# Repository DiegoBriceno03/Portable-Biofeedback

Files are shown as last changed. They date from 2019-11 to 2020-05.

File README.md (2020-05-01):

# Portable Biofeedback Device Repository

A repository that stores hardware and software files developed for the Portable Biofeedback Device, as worked on and built by students in the Electrical & Computer Engineering (ECE) Department of the College of Engineering & Computer Science (CECS) at the University of Central Florida (UCF) in Orlando, Florida.

The accompanying Android app was developed in Android Studio 3.5.3, making use of Android SDK/API 21 (Android 5).

All the schematics and layout is done in Kicad 5.14 along with custom libraries. These libraries are added under /Libraries.

These projects use custom path for its libraries. The custom Kicad Path variable ${KI_SDREPO} is used to increase portability. Custom variable points to the physical location of the /Libraries directory and must be declared under "Preferences > Configure Paths" setting before use.

## Group 11 Members

Roles are listed under each group member

+ Grace Brazil (EE)
  + Power circuit design
+ Diego Briceno (EE)
  + PCB design
+ Gustavo Diaz Galeas (CpE)
  + Phone app development
+ Nicholas Miller (CpE)
  + Firmware development

## Hardware

### Breakout Boards
- [x] MAX30101 Heart Rate / Pulse Oximeter Breakout Board REV -
- [x] Galvanic Skin Response Sensor (Groove Seed GSR Sensor design used: https://www.seeedstudio.com/Grove-GSR-sensor-p-1614.html.html)
- [x] Temperature Sensor Supporting Hardware
- [x] Battery Charging Managing circuit (BMS)
- [x] Power Regulation
Integration of these hardware is seen under ~/Prototyp_REV- 

## Software
### Phone App
- [x] Bluetooth backend
- [X] UI / UX

### Firmware
- [x] Heart Rate Data Processing Algorithm
- [x] Temperature Data Processing Algorithm
- [x] Galvanic Skin Resistance Data Processing Algorithm

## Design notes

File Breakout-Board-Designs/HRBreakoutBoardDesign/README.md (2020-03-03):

# MAX30101 Breakout Board

The Heart Rate Module for the biofeedback device is the MAX30101. Which comes with its internal LEDS and Photodiodes. In this library we have the layout done in KiCAD 5.1.5.

MAX30101 Breakout Schematic

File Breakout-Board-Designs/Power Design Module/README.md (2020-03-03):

# Power Design Module.

This module contains the design for the Portable biofeedback anxiety treatment device. 
It consist of a charging circuit (BQ24072) which is configured to charge a single cell LiPo(PKCELL 503035) 500mAh battery. This design takes advantage of a Micro USB charging at CV of 4.2V and CC of 500mA.

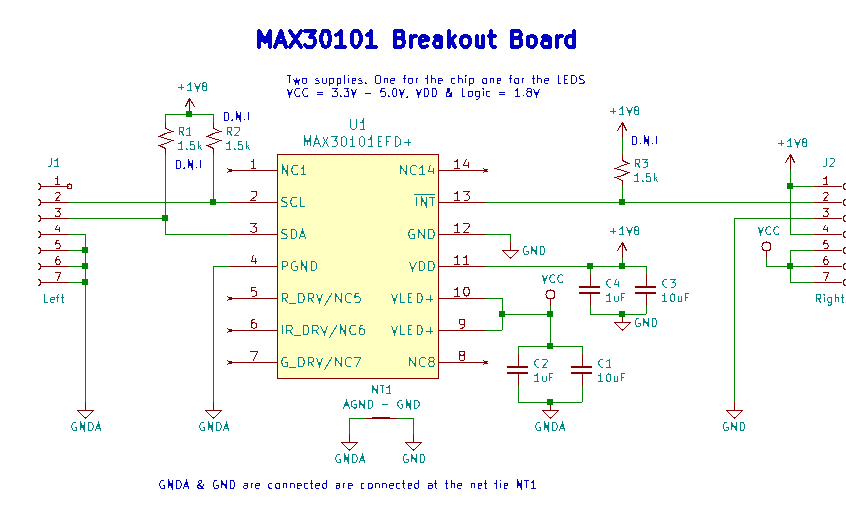
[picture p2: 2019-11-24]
Documentation/HRBreakoutBoard/Pictures/MAX30101_Schematic.png

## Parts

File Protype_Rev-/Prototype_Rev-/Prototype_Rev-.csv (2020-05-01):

Reference | Quantity | Value | Footprint | Datasheet | Manfacturing # | Rating | Tolerance | Description
C14 | 1 | 22uF | Capacitor_SMD:C_0603_1608Metric_Pad1.05x0.95mm_HandSolder | https://static6.arrow.com/aropdfconversion/3239fa20032553bf6ad0408d71d42cb72537ccc5/19-cl10a226mpcnube.pdf | CL10A226MPCNUBE | 10V
C15 | 1 | 100nF | Capacitor_SMD:C_0603_1608Metric_Pad1.05x0.95mm_HandSolder | https://www.mouser.com/datasheet/2/212/KEM_C1002_X7R_SMD-1102033.pdf | C0603C104K8RACTU | 10V
C19 | 1 | 22nF | Capacitor_SMD:C_0603_1608Metric_Pad1.05x0.95mm_HandSolder | https://www.mouser.com/datasheet/2/212/KEM_C1002_X7R_SMD-1102033.pdf | C0603C223K4RACTU | 10V
C3 C5 C24 C30 C26 C32 C25 C27 C31 C33 C20 | 11 | 1uF | Capacitor_SMD:C_0603_1608Metric_Pad1.05x0.95mm_HandSolder | https://www.mouser.com/datasheet/2/396/taiyo_yuden_12132018_mlcc11_hq_e-1510082.pdf | LMK107B7105MAHT | 10V | 20%
C4 C6 C23 C16 C22 C21 C17 C18 | 8 | 10uF | Capacitor_SMD:C_0805_2012Metric_Pad1.15x1.40mm_HandSolder | https://www.mouser.com/datasheet/2/396/mlcc02_e-1307760.pdf | LMK212B7106KG-TD | 10V
C7 C12 C13 C11 C1 C2 C10 | 7 | 0.1uF | Capacitor_SMD:C_0603_1608Metric_Pad1.05x0.95mm_HandSolder | https://www.mouser.com/datasheet/2/212/KEM_C1002_X7R_SMD-1102033.pdf | C0603C104K8RACTU | 10V
C8 C9 C29 C28 | 4 | 4.7uF | Capacitor_SMD:C_0603_1608Metric_Pad1.05x0.95mm_HandSolder | https://www.mouser.com/datasheet/2/281/murata_03052018_GRM_Series_1-1310166.pdf | GRM188Z71A475ME15D | 10V
D1 D2 D3 | 3 | DESD5V0S1BB-7 | Diode_SMD:D_SOD-523 | https://www.mouser.com/datasheet/2/115/DESD5V0S1BB-218358.pdf | DESD5V0S1BB-7
D5 D4 D6 | 3 | Red | LED_SMD:LED_0603_1608Metric_Pad1.05x0.95mm_HandSolder | https://www.mouser.com/datasheet/2/348/smld12-e-1510650.pdf | 599-0110-007F
D7 | 1 | Green | LED_SMD:LED_0603_1608Metric_Pad1.05x0.95mm_HandSolder | https://www.mouser.com/datasheet/2/348/smld12-e-1510650.pdf | SMLD12EN1WT86
J1 | 1 | USB_B_Micro | Connector_USB:USB_Micro-B_Molex-105017-0001 | ~ | 105017-0001
J2 | 1 | Interface Hub | 1053141114:1053141110 | https://www.molex.com/pdm_docs/sd/1053141114_sd.pdf
J3 | 1 | Conn_01x02 | Connector_JST:JST_EH_B3B-EH-A_1x03_P2.50mm_Vertical | https://www.digikey.com/product-detail/en/jst-sales-america-inc/B3B-EH-A-LF-SN/455-1612-ND/926521
JP1 | 1 | TMR OFF | Jumper:SolderJumper-2_P1.3mm_Open_RoundedPad1.0x1.5mm | ~
JP2 | 1 | Charger / Battery Bypass | Connector_PinHeader_2.54mm:PinHeader_1x03_P2.54mm_Vertical | ~
L1 | 1 | 1uH | IHLP2020BZER1R0M0:IHLP2020BZER1R0M01 | https://www.vishay.com/docs/34253/ihlp-2020bz-01.pdf | IHLP2020BZER1R0M01
NT1 | 1 | AGND - GND | NetTie:NetTie-2_SMD_Pad0.5mm | ~
Q1 Q2 | 2 | SS8050-G | Package_TO_SOT_SMD:SOT-23 | https://www.mouser.com/datasheet/2/80/SS8050-G_RevA181526-1481562.pdf | SS8050-G
Q3 | 1 | 2N7002ET7G | Package_TO_SOT_SMD:SOT-23 | https://www.mouser.com/datasheet/2/308/2N7002E-D-1571276.pdf | 2N7002ET7G
Q4 | 1 | BSS83P | Package_TO_SOT_SMD:SOT-23 | https://www.mouser.com/datasheet/2/196/BSS83P_Rev1_6-1730820.pdf | BSS83P
R11 R10 R35 | 3 | 530R | Resistor_SMD:R_0603_1608Metric_Pad1.05x0.95mm_HandSolder | ~ | RN731JTTD5300F100
R12 R13 | 2 | 4.7k | Resistor_SMD:R_0603_1608Metric_Pad1.05x0.95mm_HandSolder | ~ | SFR03EZPF4701
R18 R17 R30 R31 R33 R34 R39 R40 R43 R44 | 10 | 100k | Resistor_SMD:R_0603_1608Metric_Pad1.05x0.95mm_HandSolder | ~ | CRCW0603100KFKEAC
R20 R15 R19 R14 R37 | 5 | 200k | Resistor_SMD:R_0603_1608Metric_Pad1.05x0.95mm_HandSolder | ~ | SDR03EZPF2003
R21 | 1 | 1M | Resistor_SMD:R_0603_1608Metric_Pad1.05x0.95mm_HandSolder | ~ | RC0603FR-071ML
R22 R23 R5 | 3 | 1.5k | Resistor_SMD:R_0603_1608Metric_Pad1.05x0.95mm_HandSolder | ~ | RC0603FR-071K5L | 1/8W
R3 | 1 | 22.1k | Resistor_SMD:R_0603_1608Metric_Pad1.05x0.95mm_HandSolder | https://www.mouser.com/datasheet/2/427/dcrcwe3-1762152.pdf | CRCW060322K1FKEB
R32 | 1 | 1.78k | Resistor_SMD:R_0603_1608Metric_Pad1.05x0.95mm_HandSolder | ~ | CR0603-FX-1781ELF
R36 | 1 | 320R | Resistor_SMD:R_0603_1608Metric_Pad1.05x0.95mm_HandSolder | ~ | RT0603DRE07320RL
R38 | 1 | 49.9k | Resistor_SMD:R_0603_1608Metric_Pad1.05x0.95mm_HandSolder | ~ | CRCW060349K9FKEAC
R4 | 1 | 47.5k | Resistor_SMD:R_0603_1608Metric_Pad1.05x0.95mm_HandSolder | https://www.mouser.com/datasheet/2/427/crcwce3-1762584.pdf | CRCW060347K5FKEAC
R6 R29 | 2 | 2K | Resistor_SMD:R_0603_1608Metric_Pad1.05x0.95mm_HandSolder | ~ | RN73R1JTTD2001B25
R7 R1 R2 R28 R27 R25 R26 R24 R16 R42 R41 | 11 | 10k | Resistor_SMD:R_0603_1608Metric_Pad1.05x0.95mm_HandSolder | ~ | SG73G1JTTD1002D
R8 R9 | 2 | 0R | Resistor_SMD:R_0603_1608Metric_Pad1.05x0.95mm_HandSolder | ~ | CRCW06030000Z0EAC
SW1 | 1 | EN | Button_Switch_SMD:SW_SPST_PTS810 | https://dznh3ojzb2azq.cloudfront.net/products/Tactile/PTS810/documents/datasheet.pdf | SKRKAEE020
SW2 | 1 | BOOT | Button_Switch_SMD:SW_SPST_PTS810 | https://dznh3ojzb2azq.cloudfront.net/products/Tactile/PTS810/documents/datasheet.pdf | SKRKAEE020
U1 | 1 | MAX30101EFD+ | MAX30101:MAX30101EFD+ | https://datasheets.maximintegrated.com/en/ds/MAX30101.pdf
U2 | 1 | CP2102N-A01-GQFN28 | Package_DFN_QFN:QFN-28-1EP_5x5mm_P0.5mm_EP3.35x3.35mm | https://www.silabs.com/documents/public/data-sheets/cp2102n-datasheet.pdf
U3 | 1 | MAX5419LETA+ | Package_DFN_QFN:DFN-8-1EP_3x3mm_P0.5mm_EP1.66x2.38mm | https://www.mouser.com/datasheet/2/256/MAX5419-1513850.pdf
U4 | 1 | LM324 | Package_SO:TSSOP-14_4.4x5mm_P0.65mm | http://www.ti.com/lit/ds/symlink/lm2902-n.pdf
U5 | 1 | ESP32-WROOM-32 | RF_Module:ESP32-WROOM-32 | https://www.espressif.com/sites/default/files/documentation/esp32-wroom-32_datasheet_en.pdf
U6 | 1 | TPS61232DRCR | TPS61232DRCR:TPS61232DRCR | https://www.ti.com/lit/ds/symlink/tps61232.pdf
U7 | 1 | BQ24072TRGTR | BQ24072TRGTR:BQ24072TRGTR | http://www.ti.com/lit/ds/slus937c/slus937c.pdf
U8 | 1 | TLV75718PDBVR | Package_TO_SOT_SMD:SOT-23-5 | http://www.ti.com/lit/ds/symlink/tlv757p.pdf?HQS=TI-null-null-mousermode-df-pf-null-wwe&DCM=yes&distId=26
U9 | 1 | TLV75733PDBVR | Package_TO_SOT_SMD:SOT-23-5 | http://www.ti.com/lit/ds/symlink/tlv757p.pdf?HQS=TI-null-null-mousermode-df-pf-null-wwe&DCM=yes&distId=26

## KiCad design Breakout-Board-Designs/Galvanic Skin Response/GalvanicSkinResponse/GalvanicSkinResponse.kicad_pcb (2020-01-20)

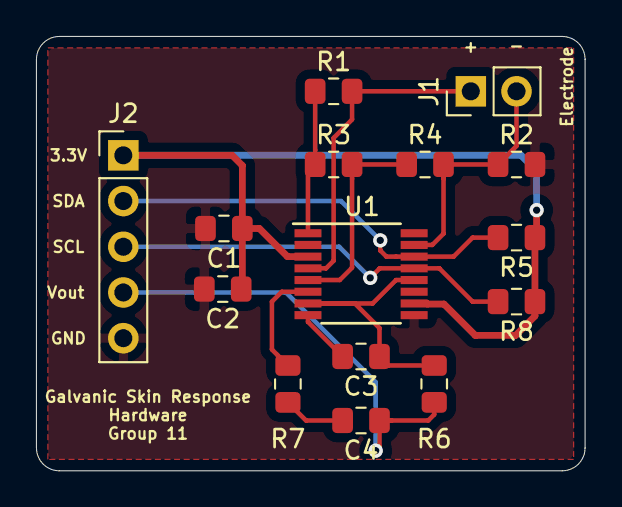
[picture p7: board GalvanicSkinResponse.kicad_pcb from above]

Board: 2 copper layers, 30.5 x 24.1 mm, 15 parts (0 on the bottom side), 13 nets.

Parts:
C1: 1nF; C_0805_2012Metric_Pad1.15x1.40mm_HandSolder
C2, C4: 10nF; C_0805_2012Metric_Pad1.15x1.40mm_HandSolder
C3: 150pF; C_0805_2012Metric_Pad1.15x1.40mm_HandSolder
J1: Electrodes; PinHeader_1x02_P2.54mm_Vertical
J2: Control; PinHeader_1x05_P2.54mm_Vertical
R1, R6, R7: 100R; R_0805_2012Metric_Pad1.15x1.40mm_HandSolder
R2: 50R; R_0805_2012Metric_Pad1.15x1.40mm_HandSolder
R3: 100k; R_0805_2012Metric_Pad1.15x1.40mm_HandSolder
R4, R5, R8: 15k; R_0805_2012Metric_Pad1.15x1.40mm_HandSolder
U1: PGA309; TSSOP-16_4.4x5mm_P0.65mm

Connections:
+3V3: C1.1, C2.1, J2.1, R5.1, R8.1, U1.3, U1.10
GND: C1.2, C2.2, J2.5, R2.2, U1.2, U1.9, U1.11
unnamed: C3.1, R6.2, U1.7, U1.12
unnamed: C3.2, U1.8
unnamed: C4.2, R7.1
unnamed: J1.1, R1.2, U1.4
unnamed: J1.2, R2.1, R4.2, U1.15
unnamed: R1.1, R3.1, U1.1
unnamed: R3.2, R4.1, U1.5
unnamed: R7.2, U1.6
SCL: J2.3, R8.2, U1.13
SDA: J2.2, R5.2, U1.14
V_out: C4.1, J2.4, R6.1

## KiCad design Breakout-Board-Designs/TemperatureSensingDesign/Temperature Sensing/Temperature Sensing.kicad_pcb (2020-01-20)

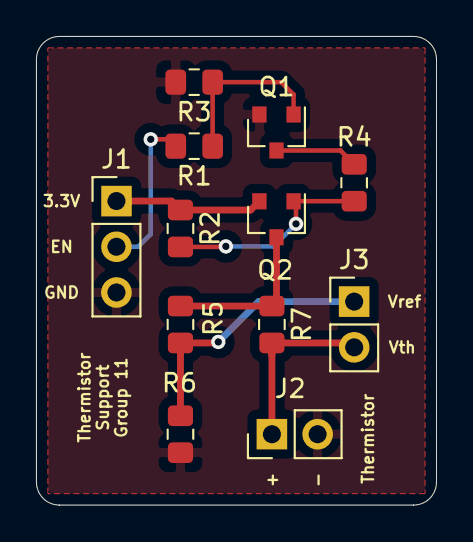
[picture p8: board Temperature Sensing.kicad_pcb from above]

Board: 2 copper layers, 22.2 x 26.0 mm, 12 parts (0 on the bottom side), 9 nets.

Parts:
J1: POW / Control; PinHeader_1x03_P2.54mm_Vertical
J2: Termistor 10k; PinHeader_1x02_P2.54mm_Vertical
J3: ADC Inputs; PinHeader_1x02_P2.54mm_Vertical
Q1: 2N7002E; SOT-23
Q2: BSS83P; SOT-23
R1, R2, R3, R4, R6: 10k; R_0805_2012Metric_Pad1.15x1.40mm_HandSolder
R5, R7: 20k; R_0805_2012Metric_Pad1.15x1.40mm_HandSolder

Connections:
/+3.3V: J1.1, Q2.2, R2.1
/GPIO_EN: J1.2, R1.2
/Vref: J3.1, R5.2, R6.1
/Vth: J2.1, J3.2, R7.2
GND: J1.3, J2.2, Q1.2, R3.2, R6.2
unnamed: Q1.1, R1.1, R3.1
unnamed: Q1.3, R4.2
unnamed: Q2.1, R2.2, R4.1
unnamed: Q2.3, R5.1, R7.1

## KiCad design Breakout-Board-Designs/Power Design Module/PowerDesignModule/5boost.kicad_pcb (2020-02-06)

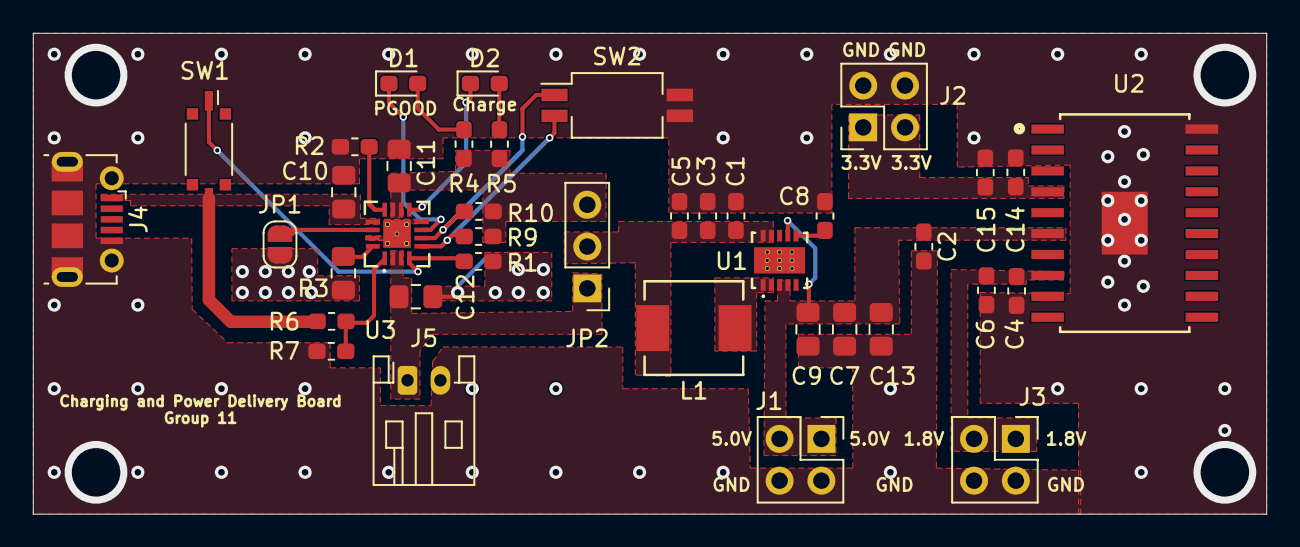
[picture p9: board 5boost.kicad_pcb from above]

Board: 2 copper layers, 74.9 x 29.2 mm, 39 parts (0 on the bottom side), 21 nets.

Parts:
C1, C3, C5: 10μF; C_0603_1608Metric_Pad1.05x0.95mm_HandSolder
C2, C4, C14: 0.1uF; C_0603_1608Metric_Pad1.05x0.95mm_HandSolder
C6, C15: 10uF; C_0603_1608Metric_Pad1.05x0.95mm_HandSolder
C7, C9, C13: 10uF; C_0805_2012Metric_Pad1.15x1.40mm_HandSolder
C8: 22nF; C_0603_1608Metric_Pad1.05x0.95mm_HandSolder
C10: 1uF; C_0805_2012Metric_Pad1.15x1.40mm_HandSolder
C11, C12: 4.7uF; C_0805_2012Metric_Pad1.15x1.40mm_HandSolder
D1: Red; LED_0603_1608Metric_Pad1.05x0.95mm_HandSolder
D2: Green; LED_0603_1608Metric_Pad1.05x0.95mm_HandSolder
J1: 5.0V; PinSocket_2x02_P2.54mm_Vertical
J2: 3.3V; PinSocket_2x02_P2.54mm_Vertical
J3: 1.8V; PinSocket_2x02_P2.54mm_Vertical
J4: USB_B_Micro; USB_Micro-B_Molex-105017-0001
J5: Battery Output; JST_PH_S2B-PH-K_1x02_P2.00mm_Horizontal
JP1: TMR OFF; SolderJumper-2_P1.3mm_Open_RoundedPad1.0x1.5mm
JP2: Charger / Battery Bypass; PinHeader_1x03_P2.54mm_Vertical
L1: 1uH; IHLP2020BZER1R0M01
R1, R2: 2K; R_0603_1608Metric_Pad1.05x0.95mm_HandSolder
R3: 1.78k; R_0805_2012Metric_Pad1.15x1.40mm_HandSolder
R4: 530R; R_0603_1608Metric_Pad1.05x0.95mm_HandSolder
R5: 320R; R_0603_1608Metric_Pad1.05x0.95mm_HandSolder
R6: 200k; R_0603_1608Metric_Pad1.05x0.95mm_HandSolder
R7: 49.9k; R_0603_1608Metric_Pad1.05x0.95mm_HandSolder
R9, R10: 10k; R_0603_1608Metric_Pad1.05x0.95mm_HandSolder
SW1: Charge Disable Switch; SW_DIP_SPSTx01_Slide_Copal_CVS-01xB_W5.9mm_P1mm
SW2: Input Current Selection; SW_DIP_SPSTx02_Slide_Copal_CHS-02B_W7.62mm_P1.27mm
U1: DRC_S-PVSON-N10; TPS61232DRCR
U2: TPPM0110DWPR
U3: BQ24072TRGTR

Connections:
/1.8V: C4.1, C6.1, J3.1, J3.2, U2.8
/3.3V: C14.1, C15.1, J2.1, J2.2, U2.4
/5.0V: C2.1, C7.1, C9.1, C13.1, J1.1, J1.2, U1.3, U1.4, U1.7, U2.6
/ChargingCircuit/BATT+: C12.1, J5.1, JP2.1, U3.2, U3.3
/Voutbat: C1.2, C3.2, C5.2, JP2.2, L1.1, U1.9, U1.10
EN1: R10.2, SW2.1, U3.6
EN2: R9.1, SW2.2, U3.5
GND: C1.1, C2.2, C3.1, C4.2, C5.1, C6.2, C7.2, C8.2, C9.2, C10.2, C11.2, C12.2, C13.2, C14.2, C15.2, J1.3, J1.4, J2.3, J2.4, J3.3, J3.4, J4.5, J4.6, J5.2, JP1.2, R1.2, R2.2, R3.2, R7.2, SW2.3, SW2.4, U1.11, U2.20, U2.21, U3.8, U3.15, U3.17
unnamed: C8.1, U1.6
unnamed: D1.1, U3.7
unnamed: D1.2, R4.2
unnamed: D2.1, U3.9
unnamed: D2.2, R5.2
unnamed: JP1.1, U3.14
unnamed: L1.2, U1.1, U1.2
unnamed: R2.1, U3.12
unnamed: R3.1, U3.16
unnamed: R6.2, R7.1, U3.1
Vbus: C10.1, J4.1, R6.1, SW1.2, U3.13
Vout: C11.1, JP2.3, R4.1, R5.1, R9.2, R10.1, U3.10, U3.11
~CE: R1.1, SW1.1, U3.4

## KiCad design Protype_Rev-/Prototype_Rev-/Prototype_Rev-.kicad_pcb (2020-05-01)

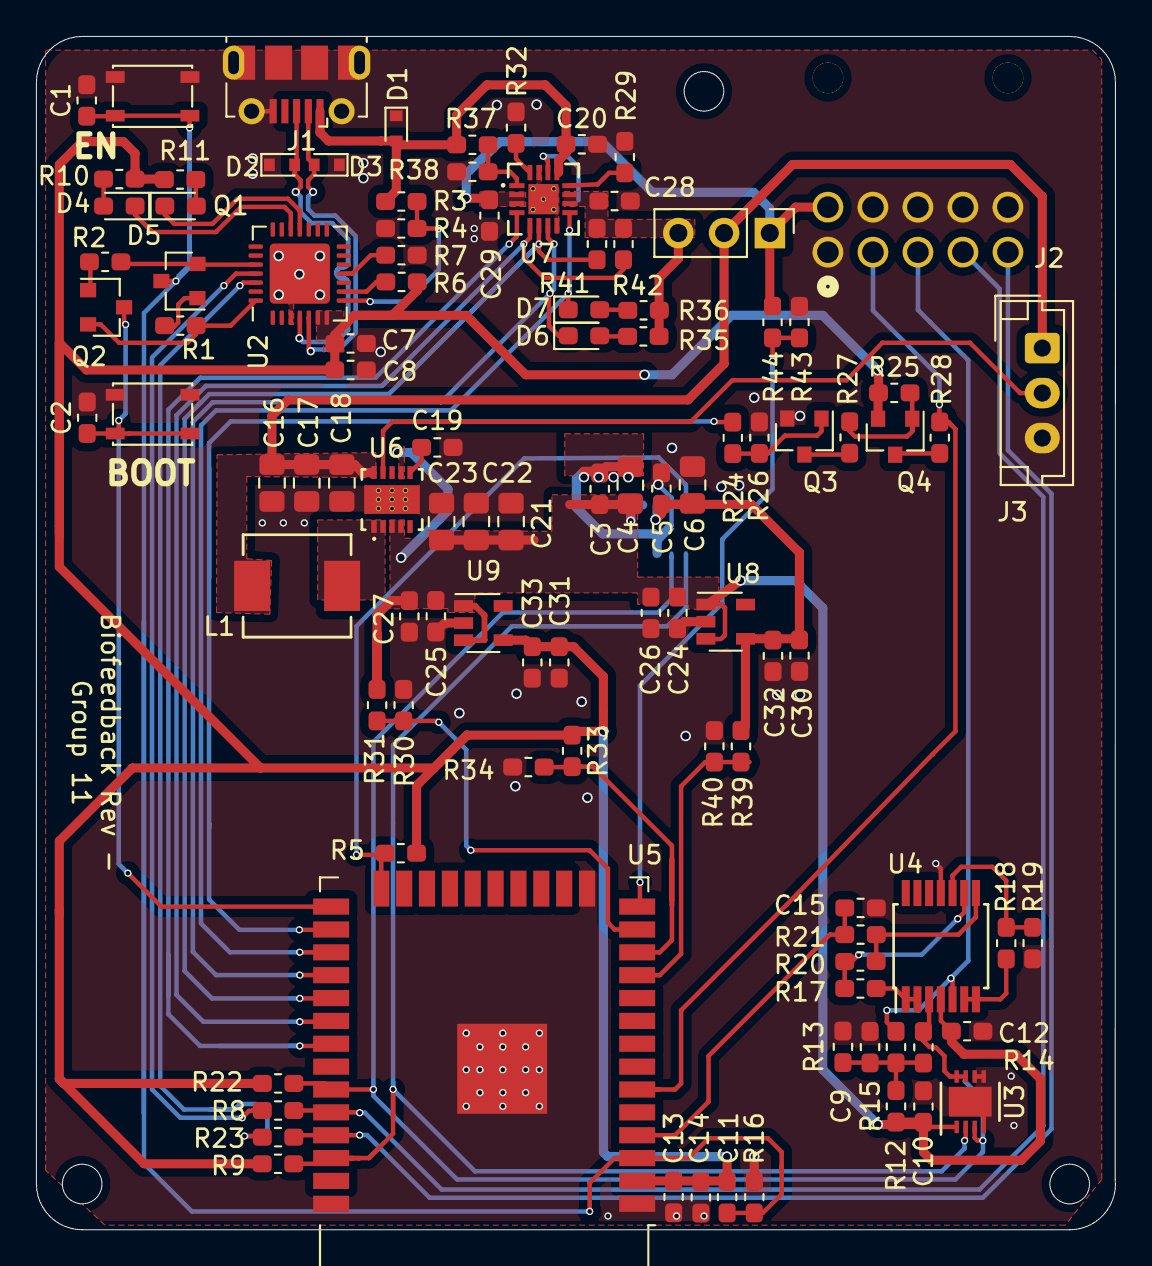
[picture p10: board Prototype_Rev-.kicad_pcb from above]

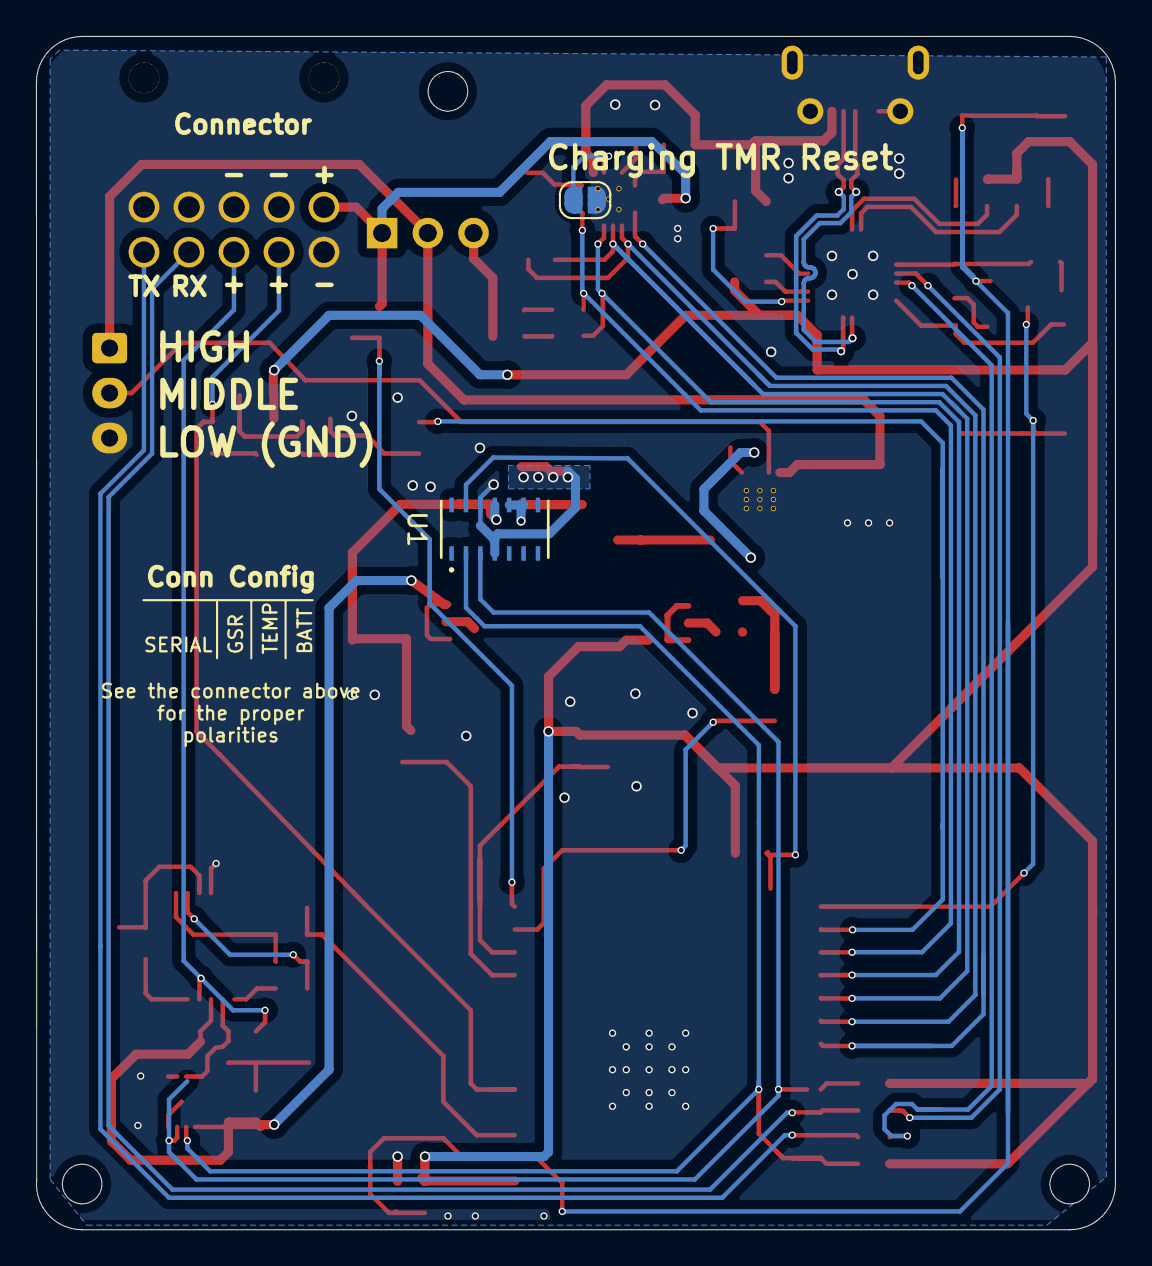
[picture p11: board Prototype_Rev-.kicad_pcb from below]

Board: 2 copper layers, 59.9 x 66.3 mm, 106 parts (3 on the bottom side), 64 nets.

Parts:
C1, C2, C7, C10, C11, C12, C13: 0.1uF; C_0603_1608Metric_Pad1.05x0.95mm_HandSolder
C3, C5, C20, C24, C25, C26, C27, C30, C31, C32, C33: 1uF; C_0603_1608Metric_Pad1.05x0.95mm_HandSolder
C4, C6, C16, C17, C18, C21, C22, C23: 10uF; C_0805_2012Metric_Pad1.15x1.40mm_HandSolder
C8, C9, C28, C29: 4.7uF; C_0603_1608Metric_Pad1.05x0.95mm_HandSolder
C14: 22uF; C_0603_1608Metric_Pad1.05x0.95mm_HandSolder
C15: 100nF; C_0603_1608Metric_Pad1.05x0.95mm_HandSolder
C19: 22nF; C_0603_1608Metric_Pad1.05x0.95mm_HandSolder
D1, D2, D3: DESD5V0S1BB-7; D_SOD-523
D4, D5, D6: Red; LED_0603_1608Metric_Pad1.05x0.95mm_HandSolder
D7: Green; LED_0603_1608Metric_Pad1.05x0.95mm_HandSolder
J1: USB_B_Micro; USB_Micro-B_Molex-105017-0001
J2: Interface Hub; 1053141110
J3: Conn_01x02; JST_EH_B3B-EH-A_1x03_P2.50mm_Vertical
JP1: TMR OFF; SolderJumper-2_P1.3mm_Open_RoundedPad1.0x1.5mm
JP2: Charger / Battery Bypass; PinHeader_1x03_P2.54mm_Vertical
L1: 1uH; IHLP2020BZER1R0M01
NT1: AGND - GND; NetTie-2_SMD_Pad0.5mm
Q1, Q2: SS8050-G; SOT-23
Q3: 2N7002ET7G; SOT-23
Q4: BSS83P; SOT-23
R1, R2, R7, R16, R24, R25, R26, R27, R28, R41, R42: 10k; R_0603_1608Metric_Pad1.05x0.95mm_HandSolder
R3: 22.1k; R_0603_1608Metric_Pad1.05x0.95mm_HandSolder
R4: 47.5k; R_0603_1608Metric_Pad1.05x0.95mm_HandSolder
R5, R22, R23: 1.5k; R_0603_1608Metric_Pad1.05x0.95mm_HandSolder
R6, R29: 2K; R_0603_1608Metric_Pad1.05x0.95mm_HandSolder
R8, R9: 0R; R_0603_1608Metric_Pad1.05x0.95mm_HandSolder
R10, R11, R35: 530R; R_0603_1608Metric_Pad1.05x0.95mm_HandSolder
R12, R13: 4.7k; R_0603_1608Metric_Pad1.05x0.95mm_HandSolder
R14, R15, R19, R20, R37: 200k; R_0603_1608Metric_Pad1.05x0.95mm_HandSolder
R17, R18, R30, R31, R33, R34, R39, R40, R43, R44: 100k; R_0603_1608Metric_Pad1.05x0.95mm_HandSolder
R21: 1M; R_0603_1608Metric_Pad1.05x0.95mm_HandSolder
R32: 1.78k; R_0603_1608Metric_Pad1.05x0.95mm_HandSolder
R36: 320R; R_0603_1608Metric_Pad1.05x0.95mm_HandSolder
R38: 49.9k; R_0603_1608Metric_Pad1.05x0.95mm_HandSolder
SW1: EN; SW_SPST_PTS810
SW2: BOOT; SW_SPST_PTS810
U1: MAX30101EFD+
U2: CP2102N-A01-GQFN28; QFN-28-1EP_5x5mm_P0.5mm_EP3.35x3.35mm
U3: MAX5419LETA+; DFN-8-1EP_3x3mm_P0.5mm_EP1.66x2.38mm
U4: LM324; TSSOP-14_4.4x5mm_P0.65mm
U5: ESP32-WROOM-32
U6: TPS61232DRCR
U7: BQ24072TRGTR
U8: TLV75718PDBVR; SOT-23-5
U9: TLV75733PDBVR; SOT-23-5

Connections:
+1V8: C5.1, C6.1, C30.1, C32.1, R39.1, U1.11, U8.4
+3V3: C7.1, C8.1, C13.1, C14.1, C31.1, C33.1, Q4.2, R5.1, R6.1, R10.1, R11.1, R16.1, R22.1, R23.1, R25.1, R33.1, U2.6, U2.7, U5.2, U9.4
+5V: C3.1, C4.1, C10.1, C12.1, C21.1, C22.1, C23.1, C24.1, C25.1, C26.1, C27.1, R12.1, R30.1, U1.9, U1.10, U3.1, U4.4, U6.3, U6.4, U6.7, U8.1, U8.3, U9.1, U9.3
/1.8V_MON: R39.2, R40.1, U5.11
/3.3V_MON: R33.2, R34.1, U5.12
/5V_MON: R30.2, R31.1, U5.13
/BATT+: C29.1, J2.6, JP2.1, R43.1, U7.2, U7.3
/BATT+_MON: R43.2, R44.1, U5.14
/CHRG_EN1: R42.2, U5.29, U7.6
/CHRG_EN2: R41.1, U5.30, U7.5
/EN: C1.1, C11.1, Q1.3, R16.2, SW1.1, U5.3
/GSR+: J2.3, R15.2, U4.5
/GSR_MON: C15.1, R21.2, U5.4
/IO0: C2.1, Q2.3, SW2.1, U5.25
/ON_OFF: J3.2, U6.9
/RXD: R8.1, U2.25
/RXD0: J2.4, R8.2, U5.34
/SCL: R23.2, U1.2, U3.2, U5.36
/SDA: R22.2, U1.3, U3.3, U5.33
/TEMP_EN: R24.2, U5.26
/TXD: R9.2, U2.26
/TXD0: J2.5, R9.1, U5.35
/USB_N: D3.2, J1.2, U2.5
/USB_P: D2.2, J1.3, U2.4
/VOUTBATT: C16.2, C17.2, C18.2, J3.1, JP2.2, L1.1, U6.10
/VTemp: J2.2, R28.2, U5.6
/Vbus: C20.1, D1.2, J1.1, R3.1, R37.1, U7.13
/~BATT_POWGOOD: D6.1, U5.28, U7.7
/~CE: U5.31, U7.4
/~CHRG: D7.1, U5.27, U7.9
/~DTR: Q2.2, R1.1, U2.28
/~INT: R5.2, U1.13, U5.24
/~RTS: Q1.2, R2.1, U2.24
GND: C1.2, C2.2, C5.2, C6.2, C7.2, C8.2, C9.2, C10.2, C11.2, C12.2, C13.2, C14.2, C15.2, C16.1, C17.1, C18.1, C19.1, C20.2, C21.2, C22.2, C23.2, C24.2, C25.2, C26.2, C27.2, C28.2, C29.2, C30.2, C31.2, C32.2, C33.2, D1.1, D2.1, D3.1, J1.5, J1.6, J2.1, J2.7, J2.8, J2.9, J2.10, J3.3, JP1.2, NT1.2, Q3.2, R4.2, R7.2, R13.2, R19.1, R26.2, R29.2, R31.2, R32.2, R34.2, R38.2, R40.2, R44.2, SW1.2, SW2.2, U1.12, U2.3, U2.29, U3.4, U3.5, U3.6, U3.9, U4.11, U5.1, U5.15, U5.38, U5.39, U6.11, U7.8, U7.15, U7.17, U8.2, U9.2
GNDA: C3.2, C4.2, NT1.1, U1.4
unnamed: C9.1, R12.2, R13.1, R14.1, R15.1
unnamed: C19.2, U6.6
unnamed: D4.1, U2.19
unnamed: D4.2, R10.2
unnamed: D5.1, U2.18
unnamed: D5.2, R11.2
unnamed: D6.2, R35.2
unnamed: D7.2, R36.2
unnamed: JP1.1, U7.14
unnamed: L1.2, U6.1, U6.2
unnamed: Q1.1, R1.2
unnamed: Q2.1, R2.2
unnamed: Q3.1, R24.1, R26.1
unnamed: Q3.3, R27.2
unnamed: Q4.1, R25.2, R27.1
unnamed: Q4.3, R28.1
unnamed: R3.2, R4.1, U2.8
unnamed: R6.2, U2.9
unnamed: R7.1, U2.11
unnamed: R14.2, U3.7, U3.8, U4.3
unnamed: R17.1, U4.1, U4.2
unnamed: R17.2, R20.1, U4.9
unnamed: R18.1, U4.6, U4.7
unnamed: R18.2, R19.2, U4.10
unnamed: R20.2, R21.1, U4.8
unnamed: R29.1, U7.12
unnamed: R32.1, U7.16
unnamed: R37.2, R38.1, U7.1
Vout: C28.1, JP2.3, R35.1, R36.1, R41.2, R42.1, U7.10, U7.11

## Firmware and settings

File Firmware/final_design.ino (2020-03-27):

// Final Design
// Nick Miller for Group 11


// Heart Rate Libraries
#include <Wire.h>
#include "MAX30105.h"
#include "heartRate.h"

// BLE Libraries
#include <BLEDevice.h>
#include <BLEUtils.h>
#include <BLEServer.h>
#include <BLE2902.h>


// Setup variables for the Thermistor
// The formula for temp in kelvin is
//                 1
// T = ----------------------------
//     1/To + (1/beta) * ln(Rt/Ro)
const int thermistorPin = 35;
float adcMax = 4095.0; // Max value of ADC, 12 bit: 0 -> 4095 
float Vs = 3.3; // Supply voltage for the voltage divider
float R1 = 9800.0;   // voltage divider resistor value
float Beta = 3950.0;  // Beta value
float To = 298.15;    // Temperature in Kelvin for 25 degree Celsius
float Ro = 10000.0;   // Resistance of Thermistor at 25 degree Celsius
float Vout, Rt, T, Tf = 0;
char string_Tf[4]; // Should be equivalent to a float (4bytes)


// Setup variables for GSR sensor
const int gsrPin = 34;
int sum = 0;
int gsrValue = 0;
int gsrAverage = 0;


// Setup Variables for Heart Rate Sensor
MAX30105 particleSensor;
const byte RATE_SIZE = 4; //Increase this for more averaging. 4 is good.
byte rates[RATE_SIZE]; //Array of heart rates
byte rateSpot = 0;
long lastBeat = 0; //Time at which the last beat occurred
float beatsPerMinute;
int previousHeartRate = 0;
int beatAvg;


// Setup variables for BLE
#define SERVICE_UUID "63228c99-ee20-4dcf-a90a-711948af59e0"
#define THERMISTOR_UUID "00002A1C-0000-1000-8000-00805f9b34fb"
#define GSR_UUID "0d823996-e5a7-4ce3-9ae3-6649d46d8f85"
#define HEARTRATE_UUID "00002A37-0000-1000-8000-00805f9b34fb"
#define BATTERY_UUID "00002A19-0000-1000-8000-00805f9b34fb"

BLECharacteristic *thermistorChar;
BLECharacteristic *gsrChar;
BLECharacteristic *heartRateChar;
BLECharacteristic *batteryChar;

uint32_t i = 0;

bool deviceConnected = false;
bool oldDeviceConnected = false;

class MyServerCallbacks: public BLEServerCallbacks {
    void onConnect(BLEServer* pServer) {
      deviceConnected = true;
    };

    void onDisconnect(BLEServer* pServer) {
      deviceConnected = false;
    }
};

void setup() {
  // Start Serial
  Serial.begin(115200);

  // Setup BLE
  Serial.println("Setting up BLE");
  
  // Setup the service
  BLEDevice::init("Group 11 BLE");
  BLEServer *pServer = BLEDevice::createServer();
  pServer->setCallbacks(new MyServerCallbacks());
  BLEService *pService = pServer->createService(SERVICE_UUID);

  // Setup the Thermistor Characteristic
//  Serial.println("1");
  thermistorChar = pService->createCharacteristic(
                                         THERMISTOR_UUID,
                                         BLECharacteristic::PROPERTY_NOTIFY |
                                         BLECharacteristic::PROPERTY_READ |
                                         BLECharacteristic::PROPERTY_WRITE |
                                         BLECharacteristic::PROPERTY_INDICATE
                                       );
  //thermistorChar->setValue(0);

  thermistorChar->addDescriptor(new BLE2902());

  // Setup the GSR Characteristic
//  Serial.println("2");
  gsrChar = pService->createCharacteristic(
                                         GSR_UUID,
                                         BLECharacteristic::PROPERTY_NOTIFY |
                                         BLECharacteristic::PROPERTY_READ |
                                         BLECharacteristic::PROPERTY_WRITE |
                                         BLECharacteristic::PROPERTY_INDICATE
                                       );
  //gsrChar->setValue(0);

  gsrChar->addDescriptor(new BLE2902());

  // Setup the Heart Rate Characteristic
//  Serial.println("3");
  heartRateChar = pService->createCharacteristic(
                                         HEARTRATE_UUID,
                                         BLECharacteristic::PROPERTY_NOTIFY |
                                         BLECharacteristic::PROPERTY_READ |
                                         BLECharacteristic::PROPERTY_WRITE |
                                         BLECharacteristic::PROPERTY_INDICATE
                                       );
  //heartRateChar->setValue(0);

  heartRateChar->addDescriptor(new BLE2902());

  // Setup the Battery Characteristic
  // Serial.println("4");
  batteryChar = pService->createCharacteristic(
                                         BATTERY_UUID,
                                         BLECharacteristic::PROPERTY_NOTIFY |
                                         BLECharacteristic::PROPERTY_READ |
                                         BLECharacteristic::PROPERTY_WRITE |
                                         BLECharacteristic::PROPERTY_INDICATE
                                       );
  //batteryChar->setValue(0);

  batteryChar->addDescriptor(new BLE2902());
  
  pService->start();
  // BLEAdvertising *pAdvertising = pServer->getAdvertising();  // this still is working for backward compatibility
  BLEAdvertising *pAdvertising = BLEDevice::getAdvertising();
  pAdvertising->addServiceUUID(SERVICE_UUID);
  pAdvertising->setScanResponse(true);
  pAdvertising->setMinPreferred(0x06);  // functions that help with iPhone connections issue
  pAdvertising->setMinPreferred(0x12);
  BLEDevice::startAdvertising();
  Serial.println("BLE Setup Complete");


  // Initialize heart rate sensor
  if (!particleSensor.begin(Wire, I2C_SPEED_FAST)) //Use default I2C port, 400kHz speed
  {
    Serial.println("MAX30105 was not found. Please check wiring/power. ");
    while (1);
  }
  Serial.println("Place your index finger on the sensor with steady pressure.");

  particleSensor.setup(); //Configure sensor with default settings
  particleSensor.setPulseAmplitudeRed(0); // Turn Red LED off
  particleSensor.setPulseAmplitudeIR(0); // Turn IR LED off
//  particleSensor.setPulseAmplitudeGreen(0); // Turn off Green LED

}

void loop() {

  i++;

//  Serial.println("Start");

  // Read the thermistor and convert it to fahrenheit

  if(!(i % 256)){
    Vout = .15 + (analogRead(thermistorPin) * Vs/adcMax); // .2 is added to make the sensor more accurate
//    Serial.println(Vout); // use to calibrate
    Rt = R1 * Vout / (Vs - Vout); 
    T = 1/(1/To + log(Rt/Ro)/Beta);  // Temperature in Kelvin
    Tf = (T - 273.15) * 9 / 5 + 32; // Convert to Fahrenheit

  // Debugging purposes
    //Serial.printf("Before Temp: %.2f\n", Tf);

    dtostrf(Tf, 4, 2, string_Tf);

  // For debugging purposes
    //Serial.printf("String Temp: %s\n", buff);
    thermistorChar->setValue(string_Tf);
    thermistorChar->notify();
  }

  
  //read the gsr sensor
  
  if(!(i % 256)){
    //reset sum
    sum=0;
    //Average the 10 measurements to remove the glitch
    for(int i=0;i<10;i++) {   
      gsrValue=analogRead(gsrPin);
      sum += gsrValue;
      delay(5);
    }
    gsrAverage = sum/10;

  // For debugging purposes
//    Serial.printf("GSR: %d\n", gsrAverage);
    gsrChar->setValue(gsrAverage);
    gsrChar->notify();
  }


  //read the heart rate sensor
  long irValue = particleSensor.getGreen();

  if (checkForBeat(irValue) == true){

//    Serial.println("found beat");
    
    //We sensed a beat!
    long delta = millis() - lastBeat;
    lastBeat = millis();

    beatsPerMinute = 60 / (delta / 1000.0);

    if (beatsPerMinute < 255 && beatsPerMinute > 20) {
      rates[rateSpot++] = (byte)beatsPerMinute; //Store this reading in the array
      rateSpot %= RATE_SIZE; //Wrap variable

      //Take average of readings
      beatAvg = 0;
      for (byte x = 0 ; x < RATE_SIZE ; x++)
        beatAvg += rates[x];
      beatAvg /= RATE_SIZE;
    }
  }

  // For debugging purposes
  //Serial.printf("Heartbeart: %d\n", beatAvg);

  // if the value is new then send it
  if(beatAvg != previousHeartRate){
    heartRateChar->setValue(beatAvg);
    heartRateChar->notify();
  }

  // set the previous
  previousHeartRate = beatAvg;
  

// left in debugging data sends for testing if needed
  
//  i++  
//  thermistorChar->setValue(i);
//  thermistorChar->notify();
//  delay(10);
//  gsrChar->setValue(i);
//  gsrChar->notify();
//  delay(10);
//  heartRateChar->setValue(i);
//  heartRateChar->notify();
//  delay(10);
//  batteryChar->setValue(i);
//  batteryChar->notify();

  //delay(2000);

}

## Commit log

2019-11-11 MAX30101 Breakout board REV- with gerbers
    [HRSensorDevBoard-B_Cu.gbr, HRSensorDevBoard-B_Mask.gbr, HRSensorDevBoard-B_SilkS.gbr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]
2019-11-11 Added remote repo to Github DiegoBriceno03/Portable-Biofeedback
    [HRSensorDevBoard-B_Cu.gbr, HRSensorDevBoard-B_Mask.gbr, HRSensorDevBoard-B_SilkS.gbr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]
2019-11-11 Added README.md
    [HRSensorDevBoard-B_Cu.gbr, HRSensorDevBoard-B_Mask.gbr, HRSensorDevBoard-B_SilkS.gbr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]
2019-11-24 Separated Breakout Board Design
    [HRSensorDevBoard-B_Cu.gbr, HRSensorDevBoard-B_Mask.gbr, HRSensorDevBoard-B_SilkS.gbr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]
2020-01-20 Power board added with temporal design and deleted charging circuit.
    [5boost.kicad_pcb, 5boost.sch, ChargingCircuit.sch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]
2020-01-21 Layout and charging circuit progress.
    [5boost.sch]
2020-01-21 Charging circuit and rough layout
    [5boost.kicad_pcb, ChargingCircuit.sch]
2020-01-21 Changes to .gitignore file
    [ChargingCircuit.sch]
2020-01-22 Finalized Charge board
    [5boost.sch, ChargingCircuit.sch]
2020-01-28 Starting Power board Layout. Design Changes
    [5boost.kicad_pcb, 5boost.sch, ChargingCircuit.sch]
2020-02-06 Final Power Breakout completed. Headers were used instead of the previous Molex Connectors
    [5boost.kicad_pcb, 5boost.sch, ChargingCircuit.sch]
2020-03-03 Final Power module and App Front end.
    [5boost.kicad_pcb, 5boost.sch, ChargingCircuit.sch]
2020-03-16 Prototype rev - completed. Connectors added and STEP file generated. Phone app progress
    [5boost.kicad_pcb, 5boost.sch, ChargingCircuit.sch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]
2020-03-18 Latest UX/UI changes.
    [Prototype_Rev-.csv, Prototype_Rev-.kicad_pcb]
2020-04-13 Changes to hierarchy.
    [5boost.kicad_pcb, 5boost.sch, ChargingCircuit.sch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]
